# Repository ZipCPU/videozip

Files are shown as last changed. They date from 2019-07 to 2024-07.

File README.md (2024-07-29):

# VideoZip

The Nexys Video board has now served me well through many funded, commercial
projects.  Many of these are SONAR projects, although there have been some
significant other projects as well--to include two separate graphics (HDMI)
projects.  The goal of this github project repository is to form a demonstration
baseline project from which a customer project, using the Nexys Video board,
can then be tailored.  As a result, part of the purpose of this project is
to demonstrate usage of all, or at least most, of the interfaces on the board.

## Capabilities

1. Debugging bus.  It's important to be able to interact with a board.  This
   interaction is possible via both UART and GbE network.

1. GPIO and SPIO: The first step to any board control is to be able to control
   individual bits.  Some bits can be simply bit-banged.  A set of these
   have been grouped together for control via a GPIO controller.  A second
   set of bits is similar, but a "Special Purpose I/O" controller has been
   built for them.  These include the LEDs, buttons, and switches.

   Since all board debugging starts with blinky, I'll list these two
   capabilities first.

2. UART: One of the first and fundamental interfaces used on all my boards is
   the UART interface.  From that interface, other interfaces can be debugged.

3. EXBUS: This is my debugging bus interface.  This particular one is a 4th
   generation interface, using a binary encoding to allow an external host
   (PC) to read and write locations on the bus.  This version should be
   a (rough) 16% faster than the last one.  (No, that's not a great
   improvement, but 16% is still 16%.)

4. MegaNet: This is my term for a Gb Ethernet (GbE) interface that handles
   a lot of packets in hardware.  Automatically handled packets include
   ARP and ICMP.  Debug packets (if enabled) are forwarded to the debug
   interface.  Everything else gets sent to the CPU's virtual packet FIFO--if
   so enabled.

5. NEXBUS: This is basically the EXBUS interface, save that it runs over a
   Gb Ethernet interface.

   This has been ported from a SONAR design, where the only access to the
   FPGA was over the Ethernet port.

6. MDIO: I have a controller to interact with the Ethernet Management Data
   Input/Output interfaces associated with the Ethernet port.  This is more
   for demonstration purposes than anything else, but it is useful when you
   want to get a design up and running and you aren't necessarily sure what
   (if anything) is wrong with the Ethernet interface.

7. VIDPIPE: Demonstrates a basic HDMI pipeline.  Video may be brought in from
   an external source, or generated locally.  An overlay may be placed on top
   of it.  The result is then send to an external HDMI output.

   Unlike prior versions of the VideoZip project, this version is designed to
   handle subclock IO synchronization delays automatically.

8. [I2C](rtl/wbi2c/wbi2ccpu.v): A key component of several projects has now
   been my "[I2C CPU](https://github.com/ZipCPU/wbi2c)".  This is
   a basic I2C controller that can run off of a script kept in memory.  It was
   initially developed for handling telemetry without CPU involvement.  With
   CPU involvement, plus one or more pre-compiled memory scripts, it's becomes
   a very capable controller.

   The Nexys Video board essentially has three separate I2C busses: two for
   the HDMI ports, and a third one for controlling Audio.  Using the script,
   the CPU can run a basic script on any HDMI insertion to read and then
   forward EDID data from the downstream HDMI to the upstream HDMI, before
   then turning on the HDMI hotplug availability signal.

   Even though the I2C controller is meant for unattended operation, it does
   have the ability to accept manual control.  Hence, a CPU can still bit-bang
   the port if desired.

9. [I2S Audio](rtl/audio/axisi2s.v).  I've got an audio capability I built
   for a SONAR test.  I've used it, and so I know it works.  However, I'm not
   (yet) certain what I'll do with it for the demo project.

10. [ZipCPU](https://github.com/ZipCPU/zipcpu): Because of course.  As the
    saying goes, if all you have is a hammer, then the whole world looks like
    a nail.  Any problem that cannot be accomplished in RTL may then be
    accomplished by the ZipCPU in software.

11. QSPI Flash controller:  This is used for both configuring the FPGA, as well
   as loading software onto the ZipCPU.

12. DDR3 SDRAM:  My intent is to use an open source DDR3 controller, although
    for now the MIG DDR3 SDRAM controller works quite nicely.

13. [SD Card](rtl/sdspi/sdio.v):  I have an
    [SDIO based controller](rtl/sdspi/sdio.v), which will replace my
    [SPI based controller](rtl/sdspi/sdspi.v) as of this release.  With the
    help of [AutoFPGA](https://github.com/ZipCPU/autofpga), I should be able to
    maintain the ability to re-enable the [SPI based
    controller](rtl/sdspi/sdspi.v) again if I so choose.  Both will allow
    access to an SD Card.

    My plan is to also include the ZipCPU [software necessary to read and write
    the SD Card here](sw/fatfs/sdiodrv.c), to the point where it may be both
    tested and proven as part of this design.

    Even better, I have the ability to read and load software from an SD card
    on startup.  This capability can go so far as to load a flash configuration
    on startup as well.  Hence, the design can start from a current flash load,
    run a small program in ROM to load a bigger program from the SD card into
    main memory, run that program, load a design configuration (i.e. bit file)
    from the SD card to flash, perhaps even loading a ZipCPU program to the
    flash as well, and then reconfigure the FPGA from flash (via the ICAPE2
    controller), so that it also starts the ZipCPU program that had been
    (just now) copied from the SD card to flash.  In the past, this approach
    has been very useful for deploying FPGA designs to customers who don't have
    access to the Vivado JTAG loader.

14. [ICAPE2](rtl/wbicapetwo.v):  My [ICAPE2 controller](rtl/wbicapetwo.v)
    provides access to the Xilinx's internal
    configuration access port.  I use this for two commands: setting the
    warm start address, and issuing IPROG requests to force the FPGA to reload
    itself.  This allows me to load the design once via JTAG, and ever
    after from the flash if desired.

    Other commands are available as well, just not as well used--such as
    reading the boot status and configuration register(s) to know the settings
    of the mode bits, or to know why a prior attempted FPGA configuration
    attempt failed.

15. [Real Time Clock](rtl/rtc/rtclight.v).  This ... is a basic real-time clock
    RTL.  It doesn't control an external clock, it doesn't run off of a
    battery, but it still generates a real time clock with subsecond level
    precision.  Three attached peripherals include a
    [stop watch](rtl/rtc/rtcstopwatch.v),
    [timer](rtl/rtc/rtctimer.v), and an
    [alarm](rtl/rtc/rtcalarm.v) based upon the real
    time clock.

    A separate [real-time date](rtl/rtc/rtcdate.v) component accompanies this clock.

    A separate [GPS enabled real-time clock](rtl/rtc/rtcgps.v) may also be
    used, although it requires set up (not included), external hardware,
    and some software to get the actual time.

16. [Wishbone SCOPE(s)](rtl/wbscope/wbscope.v):  I tend not to use vendor
    tools, such as Vivado, for any debugging purposes.  If and when I need an
    ILA, I use my own--a Wishbone scope.  Looking around, you'll find several
    examples of how Wishbone Scopes have been used in this project to debug
    various interfaces along the way.

17. [SPI CPU](rtl/wbspi/spicpu.v): Very similar to the I2C CPU is a SPI
    CPU capability.  As with the I2C CPU, this can accept and run a script
    from memory.  This component is currently wired up to control the OLED
    present on the Nexys Video board.

## Capabilities not currently included:

1. Mouse: A PS/2 capability to read from an attached mouse device has been
   removed, but may be added back into the design at a later time.

## Basic Operation

To reconfigure or adjust the configuration of the design, adjust the components
used on the AutoFPGA command line.  These are found and defined in the
[autodata/Makefile](autodata/Makefile).  This will control which components are
currently part of the design and which are not.  To reconfigure the design for
the new component set, simply then run:

    make autodata

This will recompose the bus, assign addresses as necessary, and rebuild the
[toplevel](rtl/toplevel.v) and [main](rtl/main.v) design components.  From
there, everything else needs to know what components are part of the board,
which are built into the design, etc.  Hence this will also adjust the register
mapping files in [regdefs.h](sw/host/regdefs.h) and
[regdefs.cpp](sw/host/regdefs.cpp), rebuild the linker script(s) such as
[board.ld](sw/host/board.ld), and rebuild a board definition file,
[board.h](sw/host/board.h) used by the ZipCPU.

From here, you can build a Verilog simulation via:

    make rtl
    make sim

You can then run the simulation via:

    cd sim; ./main_tb [-d] [-d] [-g] [zipcpu_program]

Options include:

- `-d` generates a trace file, whose output is controlled by the GPIO
  peripheral, allowing the CPU to determine when data gets dumped and not.

- `-d -d` forces the trace file generation for all cycles

- `-g` turns on an active simulation of the HDMI port.

- `zipcpu_program` will pre-load the flash and/or SDRAM with the given ZipCPU
  program and run it in simulation.

While the simulation is running, you can use

    telnet localhost 6783

to open a console port to the ZipCPU.

If you wish to interact with the simulation, you'll first want to build the
host access capabilities:

    make sw-host

and then set the `VIDEODEV` environment variable.  It may be set to either:

    export VIDEODEV=sim://localhost

or

    export VIDEODEV=net://localhost

depending upon whether or not you wish to access the design via the simulated
serial port, or a simulated network port.

Once done, you can use any of the programs in `sw/host` to interact with the
design.  Most common, you would use `exregs` to read and write registers
within the design.  For example, the followiong will read a variety of
registers from within the design.

    exregs VERSION
    exregs BUILDTIME
    exregs GPIO
    exregs SDRAM

The full list of named registrs can be found in
[regdefs.cpp](sw/host/regdefs.cpp).

If you wish to build the design and load it onto hardware, the same interface
is available but the setup is just a touch different.

To use the serial port to access the design, you'll first need to run
[exuart](sw/host/exuart.v).  This accepts one argument specifying the
terminal device your component is connected to, such as:

    exuart /dev/ttyUSB2

Once this program starts, you'll want to leave it running.  You can then
adjust the environment to:

    export VIDEODEV=uart://localhost

Once done, the same access commands should then work again.

While [exuart](sw/host/exuart.cpp) is running, you may access the console
port of the ZipCPU running on the Nexys Video board the same as before:

    telnet localhost 6783

To interact with the design via the network port, you'll need its IP address.
This is currently set in [autodata/meganet.txt](autodata/meganet.txt).  As of
this writing, the IP address is fixed at `192.168.15.29`, but can easily be
changed there.  Assuming you keep this IP address the same, you'll need to
let the software know where to find it:

    export VIDEODEV=net://192.168.15.29

Once done, the host commands, such as [exbus](sw/host/exbus.cpp), should work
again.

One very useful command is the [zipload](sw/host/zipload.cpp) command.  This
command loads ZipCPU software onto the board--whether to RAM or flash, as
determined by the linker script used to build the program.  If given the `-r`
option, [zipload](sw/host/zipload.cpp) will also start the ZipCPU running
the given program as well.

Particular demonstration programs include:

- [cputest](sw/board/cputest.c): Simply tests the ZipCPU, making sure all the
  instructions work.

- [contest](sw/board/contest.c): Looks for all of the various peripherals that
  have been built into the board, and attempts to verify that the CPU can reach
  out and touch each of them.

- [helloworld](sw/board/helloworld.c): A basic program, built upon the
  C-library, that just prints "Hello, World!" to the console port.

- [memtest](sw/board/memtest.c): Tests the DDR3 SDRAM memory.

- [sdreadd](sw/board/sdreadd.c): Verifies that the directory of the SD card can
  be read from.

## Status

The design is currently coming out of a massive rewrite.  Those simulations
that have been built, work.  It's now time for hardware testing.  While the
design's bit file can be built via Vivado, testing it will be next.

## License

This project is released under the GPL v3.  Should this license be insufficient
for your needs, please contact Gisselquist Technology, LLC, to discuss other
options.

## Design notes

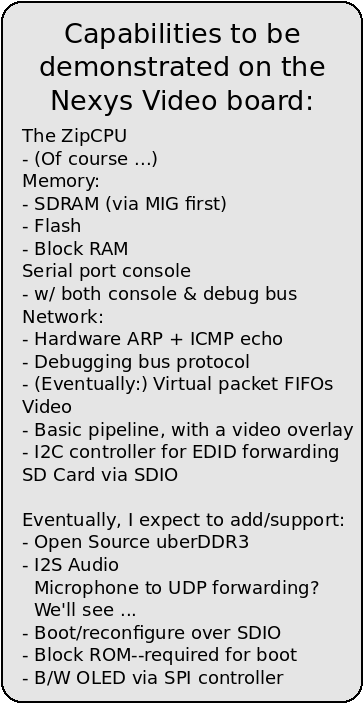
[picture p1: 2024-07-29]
doc/capabilities.png

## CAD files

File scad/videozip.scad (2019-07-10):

include <GT.scad>
include <zipcpu.scad>
include <vziplogo.scad>

module videozip() {
	// Top left is power, right side is the FMC connector
	dim = 134.5;
	height = 10;
	tol = 0.1;

	module cutout(x, y, w, h, v) {
		ex = 1.5;
		translate([x-ex/2,y-ex/2,-tol/2])
			cube([w+ex,h+ex,v+tol]);
	}

	module keepit(x, y, w, h, v) {
		ex = -1.5;
		translate([x-ex/2,y-ex/2,-tol/2])
			cube([w+ex,h+ex,v+tol]);
	}

	module	oledcutout() {
		h = height+0.1;
		lft = 51.05;
		rht = 82.80;
		bot = 25.5;
		top = 37.0;
		//
		lftx = lft-1.20*h;
		rhtx = rht+0.65*h;
		botx = bot-0.50*h;
		topx = top+1.80*h;

		// OLED
		cutout(51.05,25.5,31.75,11.5, h);
		// Build a ramp around the OLED
		/*
		polyhedron(
			points = [
				// Start with the base
				[ lft, bot, -0.05 ],	// Bottom left
				[ rht, bot, -0.05 ],	// Bottom right
				[ rht, top, -0.05 ],	// Top right
				[ lft, top, -0.05 ],	// Top left
				// Now the points on the top
				[ lftx, botx, h ],	// Bottom left
				[ rhtx, botx, h ],	// Bottom right
				[ rhtx, topx, h ],	// Top right
				[ lftx, topx, h ]	// Top left
				], faces = [
				[ 0, 1, 2, 3 ],
				[ 0, 1, 5, 4 ],
				[ 1, 2, 6, 5 ],
				[ 2, 3, 7, 6 ],
				[ 3, 0, 4, 7 ],
				[ 4, 5, 6, 7 ]
				// Now for the corners
				// [ 0,  8, 4, 12 ],
				// [ 1,  9, 5, 13 ],
				// [ 2, 10, 6, 14 ],
				// [ 3, 11, 7, 15 ]
				], convexity=3);
		*/
	}

	module layer(n) {
		base = (n==0) ? 0
			: (n == 1) ? 1.5
			: (n == 2) ? 2.4
			: (n == 3) ? 5.0
			: (n == 4) ? 5.95
			: (n == 5) ? 6.65
			: (n == 6) ? 7.0
			: (n == 7) ? 7.8
			: height;

		ztmp = (n==0) ? 1.5
			: (n==1) ? 2.4
			: (n==2) ? 5.0
			: (n==3) ? 5.95
			: (n==4) ? 6.65
			: (n==5) ? 7.0
			: (n==6) ? 7.8
			: height;

		zh = ztmp - base;
		above = height;

		// Heat sink
		cutout(78.35-21.5,78.6-23.05,21.5,23.05, above);

		// Switches
		cutout(85.9-61.7, 0, 61.7, 13.25, above);

		// LEDs
		cutout(26.40,16.75,1,3,above);
		cutout(34.40,16.75,1,3,above);
		cutout(42.40,16.75,1,3,above);
		cutout(50.40,16.75,1,3,above);
		cutout(58.40,16.75,1,3,above);
		cutout(66.40,16.75,1,3,above);
		cutout(74.40,16.75,1,3,above);
		cutout(82.40,16.75,1,3,above);

		
		//translate([85.9-61.7,-tol/2,-tol/2])
		//	cube([61.7,13.25+tol,h+tol]);
		// JP3
		cutout(39-3.0,43.1-7.41,2.5,7.41, above);
		// XADC J18
		cutout(dim-44.5,39.2-5,7.4,5, above);
		// Jumper JP1, mid sound
		// cutout(104.75-2.0,113,2.5,6, above); // This was way too low
		cutout(104.75-2.0,117.4,2.5,4.4, above);
		// Prog button Lower reset
		cutout(dim-34.3,84.6-4.6,4.6,4.6, above);
		// Top reset
		cutout(dim-34.3,93.8-4.6,4.6,4.6, above);
		// Jumper
		cutout(dim-50.2,84.45-2.5,9.9,2.5, above);
		// S button
		cutout(106.5-4.6,11.5-4.6,4.6,4.6, above);
		// N button
		cutout(106.5-4.6,29.5-4.6,4.6,4.6, above);
		// W button
		cutout(93,15.9,5,5, above);
		// E button
		cutout(111,15.9,5,5, above);
		// M button
		cutout(102,15.9,5,5, above);
		// Pwr and pwr switch
		cutout(0,117-16.3,14.8,16.3, above);
		// Pwr LED
		cutout(5,95.75,2.5,1.5, above);

		// Battery jumper (next to power supply)
		cutout(0,dim-11,6.5,11-7.3, above);

		// Ethernet @ 13.65
		cutout(71.37-17,dim-21.4,18,21.4, above);

		// HDMI LED
		cutout(27.35,127.4,2.5,2.0, above);

		// Network LED(s)
		// cutout(78,108.0,2.5,0.8, above);
		// cutout(78,110.9,2.5,0.8, above);
		// cutout(78,113.7,2.5,0.8, above);
		// cutout(78,108.0,2.5,6.5, above);	// This was too low
		cutout(78,110.0,2.5,7.5, above);

		//
		oledcutout();

		translate([0,0,base]) {
			// pad platform
			if (n == 0) {
				// Set up some pads to sit on the board
				// itself
				difference() {
					color("black") {
						cube([dim,dim,zh]);
					}
					translate([0,0,-zh/2]) {union() {
					nh = zh*2;

					// Across the bottom
					keepit(-1.5,-1.5,dim+1.5,5.5,nh);
					// Below the right corner
					keepit(110,0,21,9,nh);
					// Bottom right, before PMod
					keepit(dim-8,0,10,12.5,nh);

					// Right of the USBs
					keepit(6,18,8,15,nh);

					// Above the switches, below the LEDs
					keepit(20,13.25,68,3,nh);
					// Above the switches, below the LEDs
					keepit(20,20,68,3,nh);
					// Above the Bottons, on the right
					keepit(109,24,12,12,nh);
					// Left of the FMC
					keepit(108,30,12,70,nh);
					// On top of Nexys Label
					keepit(40,38,48,11,nh);
					// On top of Digilent Label
					keepit(80,58,40,19,nh);
					// On top of Xilinx Label
					keepit(14.3,89,47-14.3,12,nh);
					// Below the sound ports
					keepit(83,dim-19,99-83,8,nh);
					// Between the HDMI ports
					keepit(18.6,dim-11.5,60-18.6,13,nh);
					// Below the HDMI ports
					keepit(33,dim-19,50-33,7,nh);
					// Between USB and first left PMod
					keepit(-3,48,10,9,nh);
					// Between the two left PMods
					keepit(-2,72,12,8,nh);
					// Between right PMod and FMC
					keepit(112,23,136-112,42,nh);
					// Between FMC and PMod JXADC
					keepit(112,85,136-112,103-85,nh);
					// Between PMod JXADC and the screw
					keepit(dim-6,dim-14,10,14,nh);
					cutout(dim-12,dim-30.3,12,16,zh);
					// Left of the big yellow component
					keepit(19.5,63.5,30-19.5,67.8-63.5,nh);
					// Above the power connector
					keepit(-2,117,27.5,124-117,nh);
					// Between the sound ports
					keepit(76.5,dim-8,50,12,nh);
					}}
				}
			}

			if (n <= 1) {
				// PROG USB @ 2.4
				cutout(0,16.75-8.5,5.4,7.5,zh);
				// UART USB
				cutout(0,28.3-7.5,5.4,7.5,zh);

				// Screws
				cutout(0,0,7,7,zh);
				cutout(dim-7,0,7,7,zh);
				cutout(dim-7,dim-7,7,7,zh);
				cutout(0,dim-7,7,7,zh);

			}

			if (n <= 2) {
				// 5mm
				// Lower right PMod HA @ 4.95
				cutout(dim-12,30.6-16,12,16,zh);
				// Upper right PMod JXADC
				cutout(dim-12,dim-30.3,12,16,zh);
				// PMod JB
				cutout(0,72-16,12,16,zh);
				// PMod JC
				cutout(0,95-16,12,16,zh);
				// Large components
				cutout(29.5,61,49.5-29.5,74-61,zh);
				cutout(13.5,61,19.5-13.5,74-61,zh);
				cutout(15,
					43.5,
					5,50.3-43.5,zh);
				// Under second X in Xilinx, above FPGA
				cutout(52.7,83,61-52.7,92-83,zh);
				// Behind the Ethernet port
				cutout(66,105,73-66,5.5,zh);

			}

			if (n <= 3) {
				// 5.95mm
	
				// Sound @ 5.91
				// cutout(76.5,dim-12.2,50.1,12.2,zh);
				// Blue
				cutout( 97-7.1,dim-12.2,7.1,14,zh);
				// Pink
				cutout(107-7.1,dim-12.2,7.1,14,zh);
				// Green
				cutout(117-7.1,dim-12.2,7.1,14,zh);
				// Black
				cutout(127-7.1,dim-12.2,7.1,14,zh);
			}

			if (n <= 4) {
				// 6.6mm
				//
				// FMC connector @ 6.55
				cutout(dim-14.75,96.4-57.5,14.8,57.5,zh);
			}

			if (n <= 5) {
				// 7mm
				// Big USB, lower left @ 6.9
				cutout(0,48.6-13.4,14.6,13.4,zh);
			}

			if (n <= 6) {
				// 7.8mm
				// HDMI in @ 7.6
				cutout(8.4,dim-11.64,15.1,11.64,zh);
				// HDMI out
				cutout(33.3,dim-11.64,15.1,11.64,zh);
				// Display port out @ 7.5mm above board surface
				cutout(85.45-8.8,122,8.9,15, zh);
			}
		}
	}

	module  embossZip() {
		s = 0.8;
		depth = 1.5;
		translate([56/2, 57, height+zlogoh/2-depth]) {
			rotate([0,0,0]) scale([s,s,1]) {
				translate([-zlogow/2,(zlogob-zlogol)/2,
							-zlogoh/2])
						zipcpulogo();
			}
		}
	}

	module  embossVZip() {
		s = 1.6;
		depth = 1.5;
		translate([37, 80, height+vzlogoh/2-depth]) {
			rotate([0,0,0]) scale([s,s,1]) {
				translate([-vzlogow/2,(vzlogob-vzlogol)/2,
							-vzlogoh/2])
						vziplogo();
			}
		}
	}

	module  embossGT() {
		s = 1.6;
		depth = 1.5;
		translate([110, 58, height+gtlogo_h/2-depth]) {
			rotate([0,0,0]) scale([s,s,1]) {
				translate([-gtlogo_w/2,(-gtlogo_l)/2,
							-gtlogo_h/2])
						GTlogo();
			}
		}
	}

	difference() {
		cube([dim,dim,height]);
		layer(0);
		layer(1);
		layer(2);
		layer(3);
		layer(4);
		layer(5);
		layer(6);
		layer(7);
		embossZip();
		embossGT();
		embossVZip();
		//
		// oledcutout();
	}
}

rotate([180,0,0]) { translate([0,-152,-10]) {
	if(1) {
	intersection() {
		translate([-10,-10,-20])
			cube([155,10+72,50]);
		videozip();
	}}

	if (0) { translate([0,5,0]) {
		intersection() {
			translate([-10,36,-20])
				cube([155,36,50]);
			videozip();
		}
	}}

	if (1) { translate([0,10,0]) {
		intersection() {
			translate([-10,72,-20])
				cube([155,80,50]);
			videozip();
		}
	}}

	if (0) { translate([0,15,0]) {
		intersection() {
			translate([-10,108,-20])
				cube([155,36+20,50]);
			videozip();
		}
	}}
}}

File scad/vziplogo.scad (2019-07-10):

vzlogow = 41;
vzlogol = 9;
vzlogob = 2;
vzlogoh = 5;
module	vziplogo() {
	linear_extrude(height=vzlogoh) {
		union() {
			// V
			polygon(points=[
				[0,0],
				[1,0],
				[10,9],
				[9,9],
				[1,1],
				[4,9],
				[3,9] ]);
			// I
			polygon(points=[
				[3,0],
				[4,0],
				[11,7],
				[10,7] ]);
			// The 'D'
			polygon(points=[
				[6,0],
				[7,0],
				[13,6],
				[15,6],
				[15,5],
				[12,2],
				[10,1],
				[ 9,1],
				[ 8,0],
				[10,0],
				[12,1],
				[16,5],
				[16,7],
				[13,7],
				[ 6,0] ]);
			// The E
			polygon(points=[
				[13,0],
				[18,0],
				[19,1],
				[15,1],
				[17,3],
				[20,3],
				[21,4],
				[18,4],
				[20,6],
				[24,6],
				[25,7],
				[20,7] ]);
			// The O
			polygon(points=[
				[22,0.9],
				[22,0],
				[25,0],
				[31,6],
				[31,7],
				[27,7],
				[22,2],
				[22,1.1],
				[27,6],
				[30,6],
				[25,1] ]);
		/*
			// The Z
			polygon(points=[
				[25,-2],
				[30,-2],
				[31,-1],
				[27,-1],
				[37,9],
				[27,9],
				[26,8],
				[35,8]]);
			// The i
			polygon(points=[
				[31,0],
				[32,0],
				[34,2],
				[33,2],
				[31,0]]);
			polygon(points=[
				[34,3],
				[35,3],
				[36,4],
				[35,4] ]);
			// The p
			polygon(points=[
				[32,-2],
				[33,-2],
				[37,2],
				[40,2],
				[39,1],
				[37,1],
				[36,0],
				[39,0],
				[41,2],
				[41,3],
				[37,3] ]);
		*/
		}
	}
}

// vziplogo();
// translate([0,-vzlogob,-vzlogoh]) color("red") cube([vzlogow, vzlogol+vzlogob, vzlogoh]);

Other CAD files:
scad/GT.scad
scad/zipcpu.scad

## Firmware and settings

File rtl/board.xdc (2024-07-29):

### This file is a general .xdc for the Nexys Video Rev. A
### To use it in a project:
### - uncomment the lines corresponding to used pins
### - rename the used ports (in each line, after get_ports) according to the top level signal names in the project


## Clock Signal
## {{{
set_property -dict {PACKAGE_PIN R4 IOSTANDARD LVCMOS33} [get_ports i_clk]
create_clock -period 10.000 -name INCLK -waveform {0.000 5.000} -add [get_ports i_clk]
## }}}


## FMC Transceiver clocks (Must be set to value provided by Mezzanine card, currently set to 156.25 MHz)
## {{{
## Note: This clock is attached to a MGTREFCLK pin
#set_property -dict { PACKAGE_PIN E6 } [get_ports { GTP_CLK_N }];
#set_property -dict { PACKAGE_PIN F6 } [get_ports { GTP_CLK_P }];
#create_clock -add -name gtpclk0_pin -period 6.400 -waveform {0 3.200} [get_ports {GTP_CLK_P}];
#set_property -dict { PACKAGE_PIN E10 } [get_ports { FMC_MGT_CLK_N }];
#set_property -dict { PACKAGE_PIN F10 } [get_ports { FMC_MGT_CLK_P }];
#create_clock -add -name mgtclk1_pin -period 6.400 -waveform {0 3.200} [get_ports {FMC_MGT_CLK_P}];
## }}}


## LEDs
## {{{
## The correct voltage for the LEDs is not really given in either the LED
## circuit or the reference manual.  However, according to the schematic they
## are connected to the 2.5V bank.  Hence they are declared LVCMOS25 here.
set_property -dict {PACKAGE_PIN T14 IOSTANDARD LVCMOS25} [get_ports {o_led[0]}]
set_property -dict {PACKAGE_PIN T15 IOSTANDARD LVCMOS25} [get_ports {o_led[1]}]
set_property -dict {PACKAGE_PIN T16 IOSTANDARD LVCMOS25} [get_ports {o_led[2]}]
set_property -dict {PACKAGE_PIN U16 IOSTANDARD LVCMOS25} [get_ports {o_led[3]}]
set_property -dict {PACKAGE_PIN V15 IOSTANDARD LVCMOS25} [get_ports {o_led[4]}]
set_property -dict {PACKAGE_PIN W16 IOSTANDARD LVCMOS25} [get_ports {o_led[5]}]
set_property -dict {PACKAGE_PIN W15 IOSTANDARD LVCMOS25} [get_ports {o_led[6]}]
set_property -dict {PACKAGE_PIN Y13 IOSTANDARD LVCMOS25} [get_ports {o_led[7]}]
## }}}

## Buttons
## {{{
## The correct voltage for the buttons is VADJ.  If you adjust VADJ, adjust the
## button voltages.
set_property -dict {PACKAGE_PIN B22 IOSTANDARD LVCMOS33} [get_ports i_btnc]
set_property -dict {PACKAGE_PIN D22 IOSTANDARD LVCMOS33} [get_ports i_btnd]
set_property -dict {PACKAGE_PIN C22 IOSTANDARD LVCMOS33} [get_ports i_btnl]
set_property -dict {PACKAGE_PIN D14 IOSTANDARD LVCMOS33} [get_ports i_btnr]
set_property -dict {PACKAGE_PIN F15 IOSTANDARD LVCMOS33} [get_ports i_btnu]
#set_property -dict {PACKAGE_PIN G4  IOSTANDARD LVCMOS33} [get_ports i_cpu_resetn]
## }}}

## Switches
## {{{
## The correct voltage for the switches is VADJ.  If you adjust VADJ, adjust
## the switch voltage.
set_property -dict {PACKAGE_PIN E22 IOSTANDARD LVCMOS33} [get_ports {i_sw[0]}]
set_property -dict {PACKAGE_PIN F21 IOSTANDARD LVCMOS33} [get_ports {i_sw[1]}]
set_property -dict {PACKAGE_PIN G21 IOSTANDARD LVCMOS33} [get_ports {i_sw[2]}]
set_property -dict {PACKAGE_PIN G22 IOSTANDARD LVCMOS33} [get_ports {i_sw[3]}]
set_property -dict {PACKAGE_PIN H17 IOSTANDARD LVCMOS33} [get_ports {i_sw[4]}]
set_property -dict {PACKAGE_PIN J16 IOSTANDARD LVCMOS33} [get_ports {i_sw[5]}]
set_property -dict {PACKAGE_PIN K13 IOSTANDARD LVCMOS33} [get_ports {i_sw[6]}]
set_property -dict {PACKAGE_PIN M17 IOSTANDARD LVCMOS33} [get_ports {i_sw[7]}]
## }}}

## OLED Display
## {{{
set_property -dict { PACKAGE_PIN W22   IOSTANDARD LVCMOS33 } [get_ports { o_oled_dcn      }]; #IO_L7N_T1_D10_14 Sch=oled_dc SPI select port
set_property -dict { PACKAGE_PIN U21   IOSTANDARD LVCMOS33 } [get_ports { o_oled_reset_n  }]; #IO_L4N_T0_D05_14 Sch=oled_res RESET
set_property -dict { PACKAGE_PIN W21   IOSTANDARD LVCMOS33 } [get_ports { o_oled_sck      }]; #IO_L7P_T1_D09_14 Sch=oled_sclk SPI Clk port
set_property -dict { PACKAGE_PIN Y22   IOSTANDARD LVCMOS33 } [get_ports { o_oled_mosi     }]; #IO_L9N_T1_DQS_D13_14 Sch=oled_sdin Data port
set_property -dict { PACKAGE_PIN P20   IOSTANDARD LVCMOS33 } [get_ports { o_oled_panel_en }]; #IO_0_14 Sch=oled_vbat VBAT
set_property -dict { PACKAGE_PIN V22   IOSTANDARD LVCMOS33 } [get_ports { o_oled_logic_en }]; #IO_L3N_T0_DQS_EMCCLK_14 Sch=oled_vdd VDD
## }}}
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

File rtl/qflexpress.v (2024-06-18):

////////////////////////////////////////////////////////////////////////////////
//
// Filename:	rtl/qflexpress.v
// {{{
// Project:	VideoZip, a ZipCPU SoC supporting video functionality
//
// Purpose:	To provide wishbone controlled read access (and read access
//		*only*) to the QSPI flash, using a flash clock equal to the
//	system clock, and nothing more.  Indeed, this is designed to be a
//	*very* stripped down version of a flash driver, with the goal of
//	providing 1) very fast access for 2) very low logic count.
//
//	Three modes/states of operation:
//	1. Startup/maintenance, places the device in the Quad XIP mode
//	2. Normal operations, takes 33 clocks to read a value
//	   - 16 subsequent clocks will read a piped value
//	3. Configuration--useful to allow an external controller issue erase
//		or program commands (or other) without requiring us to
//		clutter up the logic with a giant state machine
//
//	STARTUP
//	 1. Waits for the flash to come on line
//		Start out idle for 300 uS
//	 2. Sends a signal to remove the flash from any QSPI read mode.  In our
//		case, we'll send several clocks of an empty command.  In SPI
//		mode, it'll get ignored.  In QSPI mode, it'll remove us from
//		QSPI mode.
//	 3. Explicitly places and leaves the flash into QSPI mode
//		0xEB 3(0x00) 0xa0 6(0x00)
//	 4. All done
//
// Creator:	Dan Gisselquist, Ph.D.
//		Gisselquist Technology, LLC
//
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
// This program is distributed in the hope that it will be useful, but WITHOUT
// ANY WARRANTY; without even the implied warranty of MERCHANTIBILITY or
// FITNESS FOR A PARTICULAR PURPOSE.  See the GNU General Public License
// for more details.
//
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
////////////////////////////////////////////////////////////////////////////////
//
`default_nettype	none
// }}}
// 290 raw, 372 w/ pipe, 410 cfg, 499 cfg w/pipe
module	qflexpress #(
		//
		// LGFLASHSZ is the size of the flash memory.  It defines the
		// {{{
		// number of bits in the address register and more.  This
		// controller will support flash sizes up to 2^LGFLASHSZ,
		// where LGFLASHSZ goes up to 32.
		parameter	LGFLASHSZ=24,
		// }}}
		// OPT_PIPE makes it possible to string multiple requests
		// {{{
		// together, with no intervening need to shutdown the
		// QSPI connection and send a new address
		parameter [0:0]	OPT_PIPE    = 1'b1,
		// }}}
		// OPT_CFG enables the configuration logic port, and hence the
		// {{{
		// ability to erase and program the flash, as well as the
		// ability to perform other commands such as read-manufacturer
		// ID, adjust configuration registers, etc.
		parameter [0:0]	OPT_CFG     = 1'b1,
		// }}}
		// OPT_STARTUP enables the startup logic
		// {{{
		parameter [0:0]	OPT_STARTUP = 1'b1,
		// }}}
		parameter	OPT_CLKDIV = 0,
		//
		// OPT_ENDIANSWAP.  Normally, I place the first byte read from
		// {{{
		// the flash, and the lowest flash address, into bits [7:0],
		// and then shift it up--to where upon return it is found in
		// bits [31:24].  This is ideal for a big endian systems, not
		// so much for little endian systems.  The endian swap allows
		// the bus to swap the return values in order to support little
		// endian systems.
		parameter [0:0]	OPT_ENDIANSWAP = 1'b0,
		// }}}
		// RDDELAY is the number of clock cycles from when o_qspi_dat
		// {{{
		// is valid until i_qspi_dat is valid.  Read delays from
		// 0-4 have been verified.  DDR Registered I/O on a
		// Xilinx device can be done with a RDDELAY=3.  On Intel/Altera
		// devices, RDDELAY=2 works.  I'm using RDDELAY=0 for my iCE40
		// devices
		parameter	RDDELAY = 0,
		// }}}
		// NDUMMY is the number of "dummy" clock cycles between the
		// {{{
		// 24-bits (or 32-bits) of the Quad I/O address and the first
		// data bits.  This includes the two clocks of the Quad output
		// mode byte, 0xa0.  The default is 10 for a Micron device.
		// Windbond seems to want 2.  Note your flash device carefully
		// when you choose this value.
		parameter	NDUMMY = 6,
		// }}}
		// OPT_STARTUP_FILE: For dealing with multiple flash devices,
		// {{{
		// the OPT_STARTUP_FILE allows a hex file to be provided
		// containing the necessary script to place the design into
		// the proper initial configuration.
		parameter	OPT_STARTUP_FILE="spansion.hex",
		// }}}
		//
		localparam	AW=LGFLASHSZ-2,
		localparam	DW=32
	) (
		// {{{
		input	wire			i_clk, i_reset,
		//
		// Flash memory port
		// {{{
		input	wire			i_wb_cyc, i_wb_stb, i_wb_we,
		input	wire	[(AW-1):0]	i_wb_addr,
		input	wire	[(DW-1):0]	i_wb_data,
		input	wire	[DW/8-1:0]	i_wb_sel,
		//
		output	wire			o_wb_stall, o_wb_ack,
		output	reg	[(DW-1):0]	o_wb_data,
		// }}}
		// Configuration port
		// {{{
		input	wire			i_cfg_cyc, i_cfg_stb, i_cfg_we,
		input	wire	[(DW-1):0]	i_cfg_data,
		input	wire	[DW/8-1:0]	i_cfg_sel,
		//
		output	wire			o_cfg_stall, o_cfg_ack,
		output	wire	[(DW-1):0]	o_cfg_data,
		// }}}
		// Device
		// {{{
		output	reg		o_qspi_sck,
		output	reg		o_qspi_cs_n,
		output	reg	[1:0]	o_qspi_mod,
		output	wire	[3:0]	o_qspi_dat,
		input	wire	[3:0]	i_qspi_dat,
		// }}}
		// Debugging port
		// {{{
		output	wire		o_dbg_trigger,
		output	wire	[31:0]	o_debug
		// }}}
		// }}}
	);
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

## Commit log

2017-05-02 Removed EQSPI-flash code from this basic QSPI flash driver code
2017-05-02 Added I2C and duplexd bus capability to testbench.
2017-05-02 Made the HDMI OUT I2C size variable
2017-05-02 Working I2C master controller
2017-05-02 Changed RTL, split bus console, new I2C slave, etc.
2017-05-02 Current regdefs outputs from autofpga
2017-05-08 Added better error handling to the i2c master
2017-05-08 Added the ability to extract pixels from a frame
2017-11-23 Updated UARTs to match repository
2017-11-23 Updated I2C code to match repo
2017-11-23 Tried to fix a corner case in the bus expander
2018-03-08 Added a debug trace scope to the project
2018-03-08 Updated board.xdc file for ethernet ports
2018-03-08 Removed extra debugging from the dbluartsim, fixed hangup issues
    [dbluartsim.cpp]
2019-07-10 Added (working) SCAD files to protect the board
    [GT.scad, videozip.scad, vziplogo.scad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]
2024-07-13 WIP: DBGBUS+NEXBUS now work
    Includes ExBus UART handling updates.
    - FIX: Voltage definitions for LEDs, Switches, and Buttons
    [board.xdc, dbluartsim.cpp]
2024-07-15 NEW: Read SD Card directory works in simulation w/ SDIO driver
2024-07-15 NEW SDIOSIM: Switch command works, allowing HS mode
2024-07-15 SDIO: Cleaned up debugging statements from model & driver
2024-07-28 WIP: Design now implements, but still fails timing
    [board.xdc, nexysv.xdc]
2024-07-29 NEW: BW-OLED uses SPI CPU (untested) + GPIO

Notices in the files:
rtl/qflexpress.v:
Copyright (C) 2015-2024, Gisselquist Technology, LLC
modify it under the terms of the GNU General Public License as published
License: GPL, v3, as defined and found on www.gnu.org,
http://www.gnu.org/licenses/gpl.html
